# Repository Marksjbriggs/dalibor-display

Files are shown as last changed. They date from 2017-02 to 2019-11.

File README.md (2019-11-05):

# dalibor-display
This is a 6 Nixie Tube driver board. It is old and has bugs. There is a 2 Nixie Tube driver board here: https://github.com/jdbrinton/dalibor-display/tree/two-tube. It is much more up-to-date, has several bug fixes, and example software.

UPDATE: The board has been tested good. However there's a yet-to-be debugged issue where it only operates between ~8 and ~10 Volts. EMI is suspect. Needs more debugging, but other than that board works fine.

Arduino code is attached for making your own display array.

## Overview

This is a 6 Nixie Tube driver board driven by two 170V power supplies and two open-collector drivers (3 tubes on each driver). It is designed for the Dalibor Farny R|Z568M numberical Nixie Tube. If you have a custom Nixie Tube or a Nixie Tube from another vendor you should verify that it is compatible.

## Connections

There are two 5-pin 0.1 inch pitch headers on the back which may be used to daisy-chain a number of these boards together. The open-collector drivers use a shift register. Assert the latch pin and then clock in the data for all six Nixie Tubes and continue clocking in data for any additional boards in the daisy-chain.

This board requires up to 700mA @ 12V, so if multiple boards are daisy-chained then you might need to connect a dedicated 12V power supply to each board. Also, the M3 mount may be used as a power connector by jumpering the "solder link" on the bottom of the board (see label on bottom of board).

The 3 input signals (clock, data, latch) can be driven from 1.2V to 15V. The daisy-chain output "data pin" is 12V with a series 47k resistor. Just note this in case for some reason you're going to connect the last board of your daisy-chain back into a processor.

Input Connector:

|pin|signal|
|----|----|
|1|12 Volts|
|2|Latch|
|3|Clock|
|4|Data In|
|5|Ground|

Output (daisy-chain) Connector:

|pin|signal|
|----|----|
|1|12 Volts|
|2|Latch|
|3|Clock|
|4|Data Out|
|5|Ground|

Pin #1 is adjacent to the component designator.

## Bias Resistors

Each Nixie Tube requires an anode biasing resistor. The value of this resistor determines the cold cathode illuminance. A typical value is 8.2k ohms. If the Nixie Tube element is smaller a different resistance value may be needed.

These resistor designators are as follows:

|Designator|Tube Socket|Digit|
|----|----|----|
|R4|P1|#1|
|R10|P2|#2|
|R12|P3|#3|
|R3|P4|#4|
|R9|P5|#5|
|R11|P6|#6|

Be sure to change or experiment with different resistor values for your particular tubes. The default is 47k which is most likely too high for most elements.

## Dimensions

The board is 360mm by 75mm.

The mounting holes are designed to accomodate up to a 1/4-20 inch cap screw (1/4 inch finished hole size). Note that the mounting hole positions are not symetric:

|Y|X|
|-----|-----|
|9mm |8.5mm|
|9mm |119.5mm|
|9mm |240.5mm|
|9mm |351.5mm|
|66mm |8.5mm|
|66mm |119.5mm|
|66mm |240.5mm|
|66mm |351.5mm|

This board may be put adjacent to another board and still maintain 60mm spacing between all tubes.

## Manufacturing

If you don't have access to Altium Designer then you can take the the zip file in the output directory and just send that over to any regular PCB Manufacturer. Specify the board thickness (I used 0.092") and the color. This is a simple 2-layer board.

The Excel BOM file is a complete parts purchase list. There is a PDF of the schematics in the output directory for your reference.

## BUGS

* There's a yet-to-be debugged issue where it only operates between ~8 and ~10 Volts. EMI is suspect. Needs more debugging, but other than that board works fine.

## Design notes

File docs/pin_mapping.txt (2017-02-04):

Pin Mapping:

U1	HV1	C	0
U1	HV2	C	6
U1	HV3	C	3
U1	HV4	C	7
U1	HV5	B	0
U1	HV6	B	6
U1	HV7	X	X
U1	HV8	B	7
U1	HV9	B	3
U1	HV10	B	5
U1	HV11	B	9
U1	HV12	B	8
U1	HV13	B	2
U1	HV14	B	4
U1	HV15	B	1
U1	HV16	C	5
U1	HV17	C	9
U1	HV18	C	8
U1	HV19	C	2
U1	HV20	C	4
U1	HV21	C	1
U1	HV22	A	1
U1	HV23	A	4
U1	HV24	A	2
U1	HV25	A	8
U1	HV26	A	9
U1	HV27	A	5
U1	HV28	A	7
U1	HV29	A	3
U1	HV30	A	6
U1	HV31	A	0
U1	HV32	X	X
U2	HV1	C	0
U2	HV2	C	6
U2	HV3	C	3
U2	HV4	C	7
U2	HV5	B	0
U2	HV6	B	6
U2	HV7	X	X
U2	HV8	B	7
U2	HV9	B	3
U2	HV10	B	5
U2	HV11	B	9
U2	HV12	B	8
U2	HV13	B	2
U2	HV14	B	4
U2	HV15	B	1
U2	HV16	C	5
U2	HV17	C	9
U2	HV18	C	8
U2	HV19	C	2
U2	HV20	C	4
U2	HV21	C	1
U2	HV22	A	1
U2	HV23	A	4
U2	HV24	A	2
U2	HV25	A	8
U2	HV26	A	9
U2	HV27	A	5
U2	HV28	A	7
U2	HV29	A	3
U2	HV30	A	6
U2	HV31	A	0
U2	HV32	X	X

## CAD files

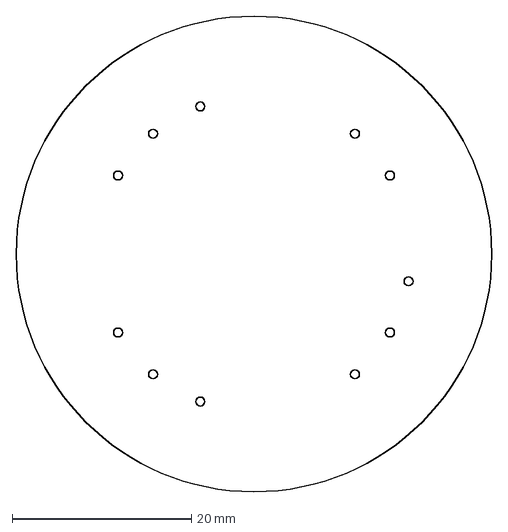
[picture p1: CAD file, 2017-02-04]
docs/rz568m.dxf
53.0 x 53.0 mm

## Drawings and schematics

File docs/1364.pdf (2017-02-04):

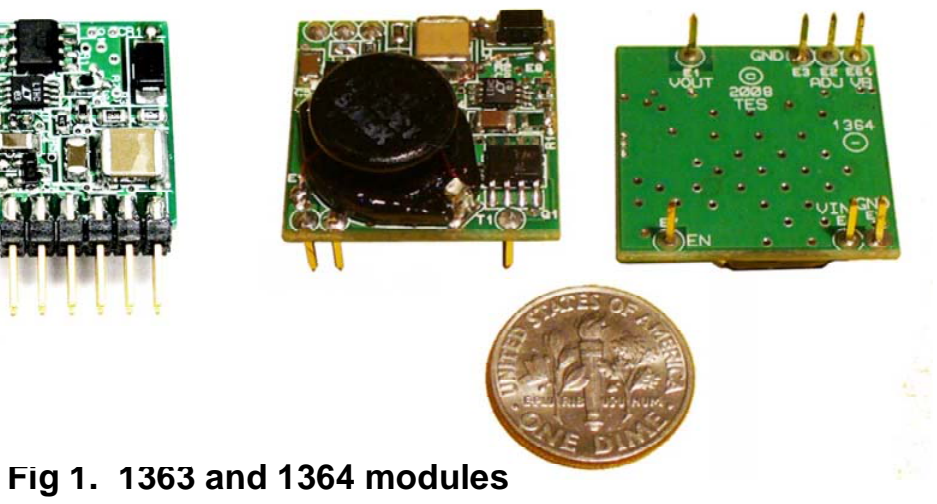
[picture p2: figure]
Fig 1. 1363 and 1364 modules
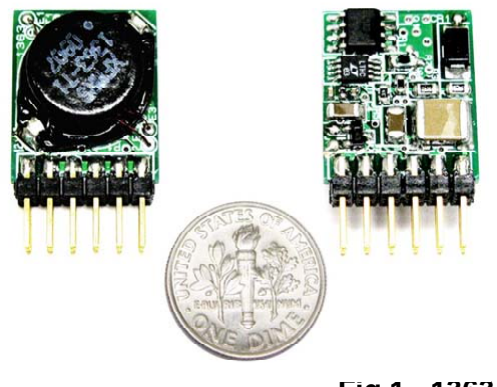
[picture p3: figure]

Taylor Electronics Services www.tayloredge.com | C 2009

# Specifications: 1363/1364 HVPS

### Rev: J

Specification | Min | Typ | Max | Units | Notes
1VIN (Input voltage) | --- | ---
| 2.00 | | 16.00 | Volts | Absolute maximum for survivability
| | | 16.00 | Volts
| | | | Volts | POUT < 4.0W (See Fig 8/9)
| | | | | POUT < 11.5W (See Fig 8/9)
2VEN-Thresh (Enable pin) | --- | --- | 0.45 | Volts
| 1.20 | --- | --- | Volts
3RADJUST | 0.00 | --- | Open | Ohms | To ground, for 200V-150V respectively
4VOUT | 150 | Volts --- | 200
Efficiency | --- | 80 | --- | % | At 50-100% rated load, VIN = 5-16VDC

### Notes:

1. No input reverse polarity protection is provided.
2. Enable pin must be driven at all times, a floating enable may destroy the module.

### Do not switch module on and off rapidly for extended periods, minimum on time should be 10 seconds. See Linear Tech LT1619 datasheet for using this pin for

clock synchronization.

### 3. RADJUST connected to ground; Gnd = 42uA / Open = 1.24V / ZIN = 30.1K. See Fig

6b for setting output voltage below 150V.
4. Output of module is short circuit protected via pulse-pulse current limiting.
5. Bias output may not be loaded at any time, for module testing only.

### Table 1: Electrical Specifications

Shutdown current | --- | uAmps | Into module: VIN=16V, VEN=0V, Tamb+85C Module off
| | | Module on, VEN-Max = VIN
VEN-Current | --- | uAmps | In-to/Out-of enable pin: VEN = 0-16V

Open > RADJUST > 0 = Ground, +/-5%

Description: The 1363/1364 series high voltage power supplies are miniature flyback boost converters operating from 2 to 16VDC input, with an output of 150 to 200VDC set by a single resistor to ground and below 150V with an external bias (See Fig 6b). An enable pin allows the module to be controlled by an external logic signal, drawing only

40uA in shut down.

--- | 40
-2 | +4

Specifications: 1363/1364 HVPS | 2

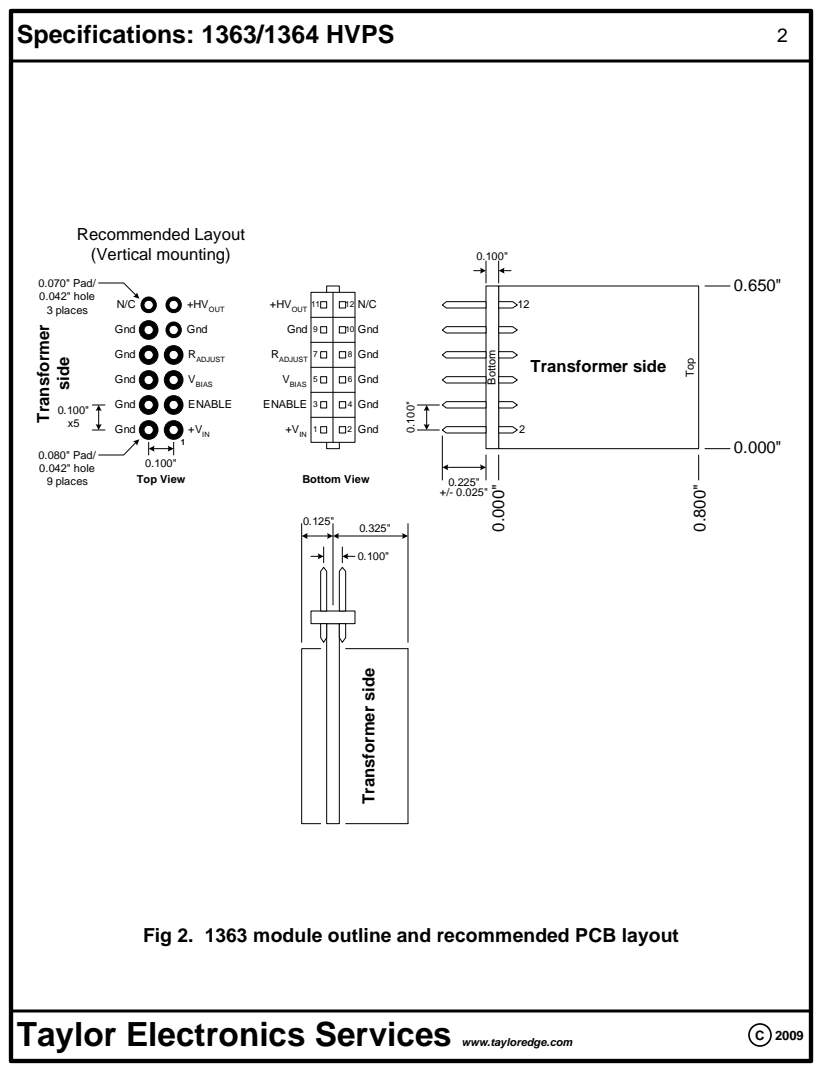
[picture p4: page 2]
+HVOUT; Gnd; +VIN; ENABLE; VBIAS; RADJUST; 0.080" Pad/ 0.042" hole 9 places; 0.070" Pad/ 0.042" hole 3 places; Recommended Layout (Vertical mounting); Transformer side; Bottom View; Bottom; Top; Top View; Transformer; side

Fig 2. 1363 module outline and recommended PCB layout

Specifications: 1363/1364 HVPS | 3

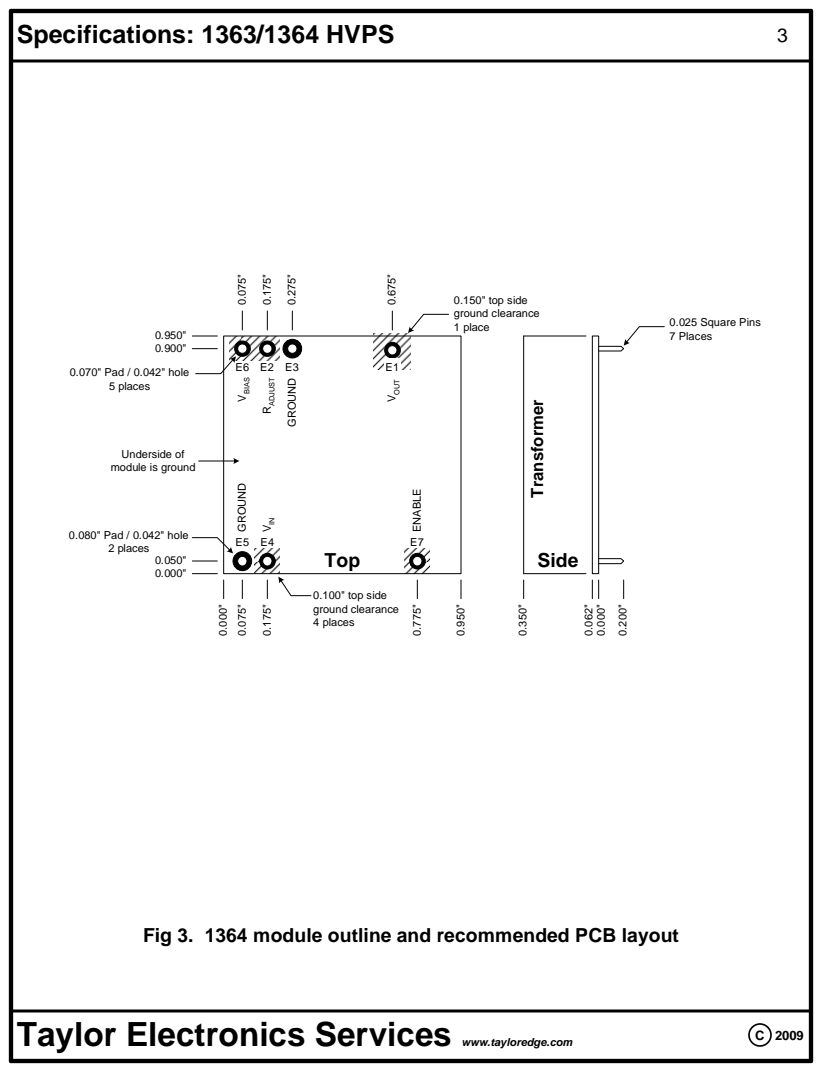
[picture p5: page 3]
0.070" Pad / 0.042" hole 5 places; 0.080" Pad / 0.042" hole 2 places; VBIAS; RADJUST; GROUND; VIN; ENABLE; VOUT; 0.150" top side ground clearance 1 place; 0.100" top side ground clearance 4 places; Transformer; Top; Side; 0.025 Square Pins 7 Places

Underside of
module is ground

Fig 3. 1364 module outline and recommended PCB layout

# Specifications: 1363/1364 HVPS

4 VIN

7 ENABLE

5 GROUND | GROUND 3 RADJUST HVOUT
| 2
1 2-16VDC in | 150-200VDC out

1.24V to VIN

RADJUST

VBIAS

6 | N/C

## Fig 4. Typical connection (1364 pin numbering shown)

## Fig 6. RADJUST calculations

## Fig 5. Enable function

VENABLE

0V

0.45V

Vin

HVOUT

0V

Vset

1.20V

### 0-0.45V = Shutdown 1.20-Vin = Enabled Shutdown current is 40uA Max @ 16V in

### Undefined operation

See: http://www.tayloredge.com/utilities/vbapps/Installers/iCalculators.exe

RADJUST (kOhms) = | 0.124 -
| -1.24
- 30.1 ( | )

The value of RADJUST can range from open to short-to-ground for 150V to 200V output respectively.

### Example, For 170V out with VADJUST = 0V: RADJUST = 48.9K to ground

Using standard 5% resistor values: 47K=170.4V, 51K=169.5V

4

330uF / 16V
EEU-FC1C331
(Recommended input capacitor if the module is located far from the main system filtering. Not required for most applications.)

## Fig 6a: VADJUST = 0V

## Fig 6b: VADJUST >= 0V

RADJUST (kOhms) = | VOUT - 1.24
1208 0.124 -

VRADJUST - 1.24

- 30.1 ( | )

The value of RADJUST can range from open to short-to-VADJUST.

### Example, For 125V out with VADJUST = 5V: RADJUST = 144.38K to 5V

Using standard 5% resistor values: 140K=124.32V, 150K=125.81V

VADJUST = 0 to 5.5V
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

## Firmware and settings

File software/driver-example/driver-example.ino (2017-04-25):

#define CLOCK 24
#define DATA  26
#define LATCH 28


#define BUFFER_SIZE      192
#define DISPLAY_SIZE     18
#define NUMBER_OF_DIGITS 10

///////////////////////////////////////////////////////////////////////////
//
// THIS IS A BUFFER POINTER MAP TO ACCESS INDIVIDUAL DIGIT ELEMENT FLAGS
//
// INDEX INTO THIS BY DIGIT AND THEN BY ELEMENT
//
///////////////////////////////////////////////////////////////////////////

uint16_t DISPLAY_MAP[DISPLAY_SIZE][NUMBER_OF_DIGITS] = {
  // CARD 3 pointers
  {223, 214, 216, 221, 215, 219, 222, 220, 217, 218},
  {197, 207, 205, 201, 206, 202, 198, 200, 204, 203},
  {193, 213, 211, 195, 212, 208, 194, 196, 210, 209},
  {255, 246, 248, 253, 247, 251, 254, 252, 249, 250},
  {229, 239, 237, 233, 238, 234, 230, 232, 236, 235},
  {225, 245, 243, 227, 244, 240, 226, 228, 242, 241},
  
  // CARD 2 pointers
  { 95,  86,  88,  93,  87,  91,  94,  92,  89,  90},
  { 69,  79,  77,  73,  78,  74,  70,  72,  76,  75},
  { 65,  85,  83,  67,  84,  80,  66,  68,  82,  81},
  {127, 118, 120, 125, 119, 123, 126, 124, 121, 122},
  {101, 111, 109, 105, 110, 106, 102, 104, 108, 107},
  { 97, 117, 115,  99, 116, 112,  98, 100, 114, 113},
  
  // CARD 1 pointers
  { 31,  22,  24,  29,  23,  27,  30,  28,  25,  26},
  {  5,  15,  13,   9,  14,  10,   6,   8,  12,  11},
  {  1,  21,  19,   3,  20,  16,   2,   4,  18,  17},
  { 63,  54,  56,  61,  55,  59,  62,  60,  57,  58},
  { 37,  47,  45,  41,  46,  42,  38,  40,  44,  43},
  { 33,  53,  51,  35,  52,  48,  34,  36,  50,  49},
  

};

///////////////////////////////////////////////////////////////////////////
//
// THIS IS A BUFFER POLARITY MAP
//
// SOME REGISTERS HAVE INVERSE POLARITY
//
///////////////////////////////////////////////////////////////////////////

char BUFFER_POLARITY[] = {
  // card 1
  1,1,1,1,1,1,1,1,1,1,1,1,1,1,1,1,1,1,1,1,1,1,1,1,1,1,1,1,1,1,1,1,
  1,1,1,1,1,1,1,1,1,1,1,1,1,1,1,1,1,1,1,1,1,1,1,1,1,1,1,1,1,1,1,1,
  
  // card 2
  0,0,0,0,0,0,0,0,0,0,0,0,0,0,0,0,0,0,0,0,0,0,0,0,0,0,0,0,0,0,0,0,
  0,0,0,0,0,0,0,0,0,0,0,0,0,0,0,0,0,0,0,0,0,0,0,0,0,0,0,0,0,0,0,0,

  // card 3
  0,0,0,0,0,0,0,0,0,0,0,0,0,0,0,0,0,0,0,0,0,0,0,0,0,0,0,0,0,0,0,0,
  0,0,0,0,0,0,0,0,0,0,0,0,0,0,0,0,0,0,0,0,0,0,0,0,0,0,0,0,0,0,0,0,
};

///////////////////////////////////////////////////////////////////////////
//
// THIS IS THE DEFAULT DISPLAY BUFFER
//
///////////////////////////////////////////////////////////////////////////

char BUFFER[] = {
  // card 1
  0,0,0,0,0,0,0,0,0,0,0,0,0,0,0,0,0,0,0,0,0,0,0,0,0,0,0,0,0,0,0,0,
  0,0,0,0,0,0,0,0,0,0,0,0,0,0,0,0,0,0,0,0,0,0,0,0,0,0,0,0,0,0,0,0,

  // card 2
  0,0,0,0,0,0,0,0,0,0,0,0,0,0,0,0,0,0,0,0,0,0,0,0,0,0,0,0,0,0,0,0,
  0,0,0,0,0,0,0,0,0,0,0,0,0,0,0,0,0,0,0,0,0,0,0,0,0,0,0,0,0,0,0,0,

  // card 3
  0,0,0,0,0,0,0,0,0,0,0,0,0,0,0,0,0,0,0,0,0,0,0,0,0,0,0,0,0,0,0,0,
  0,0,0,0,0,0,0,0,0,0,0,0,0,0,0,0,0,0,0,0,0,0,0,0,0,0,0,0,0,0,0,0,
};

void setup() {
  pinMode(CLOCK, OUTPUT);
  pinMode(DATA, OUTPUT);
  pinMode(LATCH, OUTPUT);

  //Serial.begin(9600);
}

void clearMap() {
  unsigned idx;
  
  for (idx = 0; idx < BUFFER_SIZE; idx++) {
    BUFFER[idx] = BUFFER_POLARITY[idx]?1:0;
  }
}

void setMap(unsigned digit, unsigned num) { 
  unsigned idx;
  
  idx = DISPLAY_MAP[digit][num];
  BUFFER[idx] = BUFFER_POLARITY[idx]?0:1;
}

void pushMap() {
  unsigned idx;
  for (idx = 0; idx < BUFFER_SIZE; idx++) {
    digitalWrite(CLOCK, LOW);
    delayMicroseconds(10);
    digitalWrite(DATA, BUFFER[BUFFER_SIZE - idx]);
    delayMicroseconds(10);
    digitalWrite(CLOCK, HIGH);
    delayMicroseconds(20);
  }
}

int p = 0;

void writeDigits() {
  unsigned i;
    
  // deassert latch
  digitalWrite(LATCH, HIGH);
  delayMicroseconds(10);

  // clear display buffer
  clearMap();

  //  write digits to buffer
  setMap(0, 6);
  setMap(1, 6);
  setMap(2, 6);
  setMap(3, 6);
  setMap(4, 6);
  setMap(5, 6);
  setMap(6, 6);
  setMap(7, 6);
  setMap(8, 6);
  setMap(9, 6);
  setMap(10, 6);
  setMap(11, p % 10);
  setMap(12, p % 10);
  setMap(13, p % 10);
  setMap(14, p % 10);
  setMap(15, p % 10);
  setMap(16, p % 10);
  setMap(17, p % 10);

  // push buffer to display registers
  pushMap();

  // assert latch (copy registers to latch)
  digitalWrite(LATCH, LOW);
  delayMicroseconds(10);
}


void loop() {
  //Serial.write("transmit\n\r");
  writeDigits();
  p++;
  delay(200);
}

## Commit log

2017-02-04 adding pdf schematics
2017-02-04 connectors were on wrong side of board (NOW FIXED)
    [sigsub.PcbDoc, sigsub.PrjPcb, sigsub.SchDoc]
2017-02-05 adding bias resistor to anode
    [sigsub.PcbDoc, sigsub.PrjPcb, sigsub.SchDoc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]
2017-02-05 renaming project
    [dalibor-display.PcbDoc, dalibor-display.PcbLib, dalibor-display.PrjPcb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]
2017-02-05 cleaning up parameter names
    [dalibor-display.PcbDoc, dalibor-display.PrjPcb, dalibor-display.SchDoc]
2017-04-25 adding arduino code for driving display updating readme
2019-10-10 two tube version of the original board
    [dalibor-display.PcbDoc, dalibor-display.PrjPcb, dalibor-display.SchDoc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]
2019-10-10 reverting back to original 6-tube design (forgot to branch when committing the last two tube design, so this undues that)
    [dalibor-display.PcbDoc, dalibor-display.PrjPcb, dalibor-display.SchDoc]
